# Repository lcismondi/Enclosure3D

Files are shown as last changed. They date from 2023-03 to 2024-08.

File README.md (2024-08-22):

# Enclosure3D
Me puse a diseñar un control de ambiente para un gabinete de impresión 3D y así mejorar la calidad de impresión, puedes ver más novedades en mis redes [Instagram](https://instagram.com/lucianociri) y [TikTok](https://www.tiktok.com/@luciano.ciri).

Montaje

 ### Componentes
 * NodeMCU ESP8266 (compatible con V2 y V3)
 * Display 0.91" oled
 * Sensor de humedad y temperatura DHT11 o DHT22
 * Rotary encoder

## Parámetros técnicos
* Dimensiones: 105mm x 65mm x 33mm
* Material: PLA
* Alimentación: 12v CC
* Consumo: 

## Puertos
El dispositivo presenta 3 salidas para el control de ambiente:
* Iluminación (LUZ) 12v @ 1A.
* Ventilación (VT1) 12v @ 1A.
* Ventilación (VT2) 12v @ 2A.

### Diagrama de conexionado

```mermaid
graph LR;
id0("Vcc 12v")-->id1[Enclosure3D];
id1[Enclosure3D]--pwm-->id2["Iluminación(LUZ)"];
id1[Enclosure3D]--pwm-->id3["Ventilación 1 (VT1)"];
id1[Enclosure3D]--pwm-->id4["Ventilación 2 (VT2)"];

id1[Enclosure3D]--i2c-->id5["Display 128x32"];
id6["Encoder"]-->id1[Enclosure3D];
id7["DHT"]-->id1[Enclosure3D];

```
# Proyecto
Es un proyecto Openfirmware en el cual se puede desarrollar sobre la arquitectura del ESP8266. Para saber más sobre el código puedes verlo y descargarlo desde la 
[sección de firmware](./Firmware/README.md) y si lo que más te gusta es diseñar, puedes proponer la próxima versión de la carcaza o personalizarla a tu propio estilo en la [sección de carcasa](./Carcasa/README.md).

# Compatibilidad
Como no todo sucede al mismo tiempo y en el mismo orden, veamos qué cosa es compatible con qué.

| [Firmware](./Firmware/Versiones.md) | [PCB](./PCB/VersionPCB.md)  | [Carcasa](./Carcasa/Versiones.md)  | Software |
| :--: | :--: | :--: | :--: |
| 0.0 | 0.0 | 0.0 | - |
| 0.1 | 0.1 | 0.1 | - |
| 0.2 | 0.2 | 0.2 | - |
| 0.3 | 0.3 | 0.2 | - |
| 0.4 | 0.3 | 0.2 | - |
| - | - | - | - |

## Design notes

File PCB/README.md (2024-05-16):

# Pinout

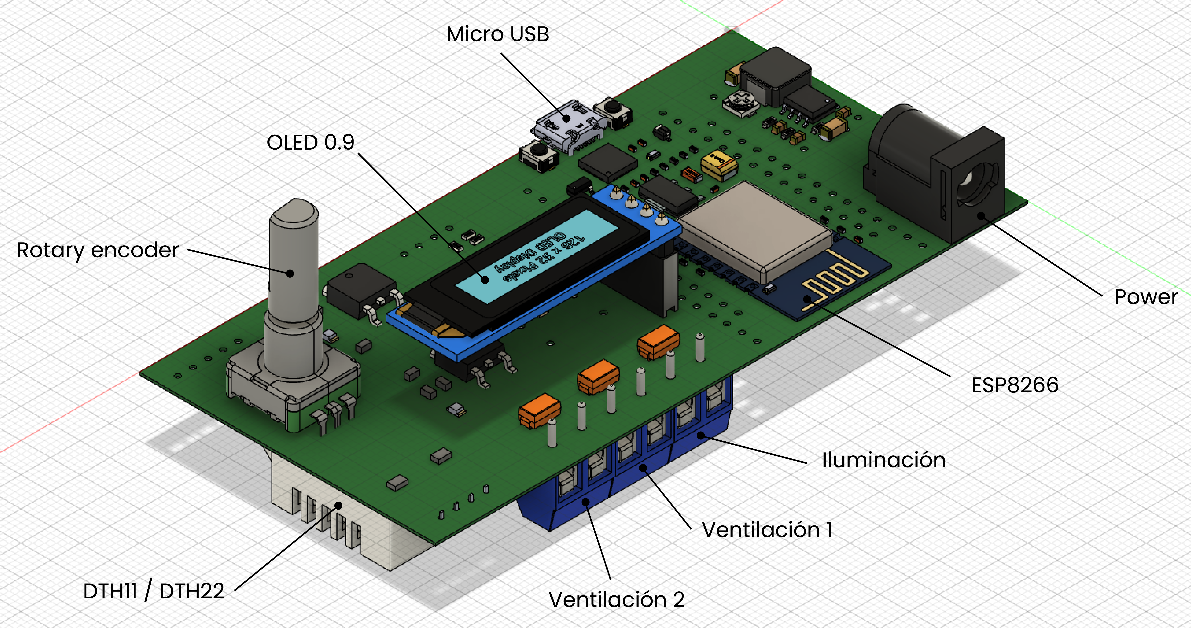
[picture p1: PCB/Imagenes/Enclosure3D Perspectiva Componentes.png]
Componentes internos


## Rotary encoder
* Switch: 13 [D7]
* Data:   12 [D6]
* Clock:  16 [D0]

## Salidas
* Iluminación:  15 [D8]
* Ventilador 1: 0  [D3]
* Ventilador 2: 14 [D5]

## Sensor
* Humedad y temperatura: 2 [D4]

## Display
* Reset: 16 [D0]
* Clock: 5  [D1]
* Data:  4  [D2]

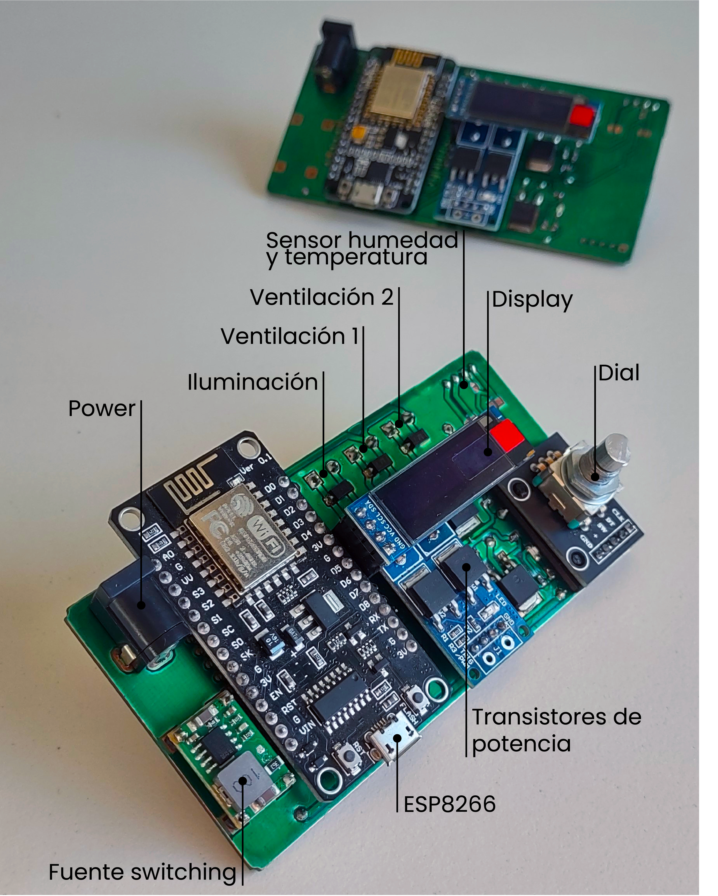
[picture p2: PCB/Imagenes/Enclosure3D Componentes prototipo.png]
Componentes prototipos


# Serigrafía
La versión de fabricación industrial tiene la capa de silkscreen mejor diseñada.

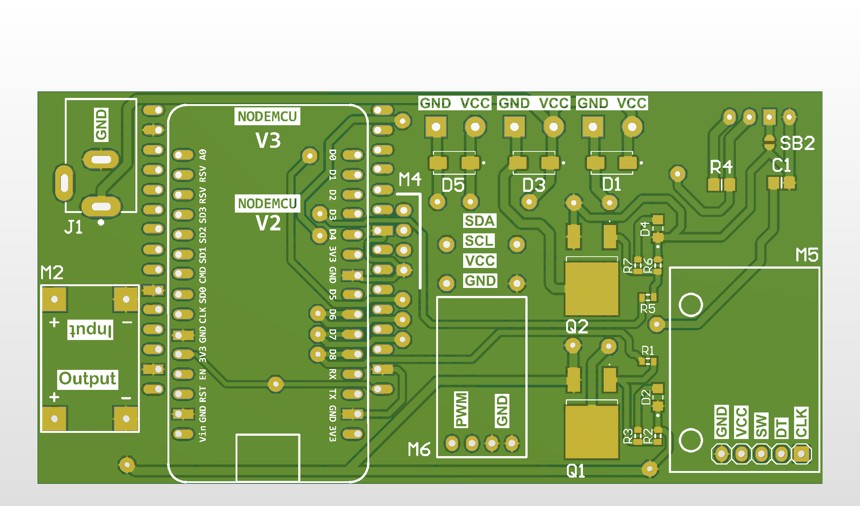
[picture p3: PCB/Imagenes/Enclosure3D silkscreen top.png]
Silkscreen top


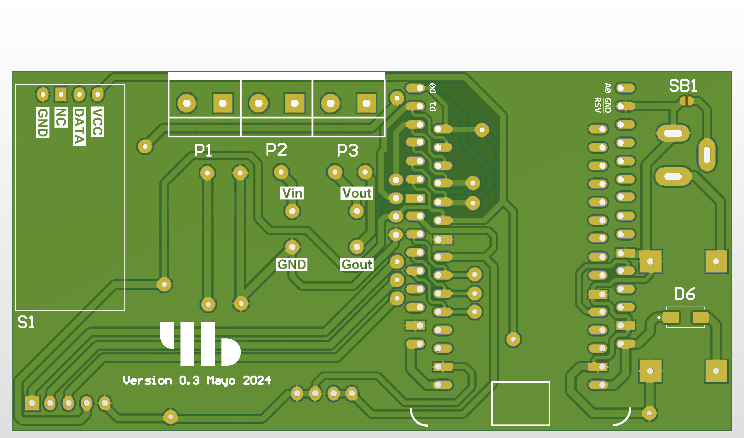
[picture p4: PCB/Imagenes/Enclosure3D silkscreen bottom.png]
Silkscreen bottom


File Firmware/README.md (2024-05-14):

# Descripción del Firmware

## Máquina de estados
El sistema está basado principalmente en una gran máquina de estados que gestiona el menú de interfaz de usuario y por otro lado la administración de la lágica de control del dispositivo.

```mermaid
graph TD;
    id0((Inicio))-->id1(Lectura botones);
    id1(Lectura botones)-->id2(Control Menú);
    id2(Control Menú)-->id3(Control lógica);
    id3(Control Lógica)-->id1(Lectura botones);
    
    id2(Control Menú)-->id4(Carrusel);
    id4(Carrusel)-->id2(Control Menú);
    
    id4(Carrusel)-->id5(Primer menú);
    id5(Primer menú)-->id4(Carrusel);
    
    id5(Primer menú)-->id6(Opción submenú);
    id6(Opción submenú)-->id5(Primer menú);
    
    id6(Opción submenú)-->id7(Configuración valores);
    id7(Configuración valores)-->id6(Opción submenú);
```

Las acciones de transición vienen dadas por el "click" del cursor de navegación dentro del menú.

## Espacios de memoria
El menú se reserva con un vector de vectores en donde todos los niveles son del mismo tamaño dado por el mayor. El final de un vector de menor tamaño lo determina la palabra clave "Volver".

| Menú  | 1° Renglon | 2° Renglon | 3° Renglon | 4° Renglon |
| :--: | :--: | :--: | :--: | :--: |
| Temperatura | Set point | Ripple | Unidad | Volver |
| Reloj|Modo | Tiempo | Reset | Volver |
| Ventilacion | Modo | Funcion | Velocidad | Volver |
| Iluminacion | Modo | Alarma | Brillo | Volver |
| *Wifi** | *Modo* | *SSIS* | *Nivel* | *Volver* |
| Sistema | Reiniciar | Encoder | Contraste | Volver |
|Salir|

**Funcionalidad no implementada*

Los valores se guardan en la memoria EEprom solo cuando sufren un cambio desde el menú de administración y se alojan en los siguientes espacios reservados:

    0x100 menuVal[0][0] = Temperatura medida
    0x104 menuVal[0][1] = Temperatura seleccionada
    0x108 menuVal[0][2] = Ripple
    0x112 menuVal[0][3] = Unidad temperatura
    0x116 menuVal[0][4] = Humedad medida
    0x120 menuVal[1][0] = -
    0x124 menuVal[1][1] = Modo reloj (Off/Cronometro/Temporizador)
    0x128 menuVal[1][2] = Tiempo en milisegundos
    0x132 menuVal[1][3] = Reset
    0x136 menuVal[1][4] = -
    0x140 menuVal[2][0] = -
    0x144 menuVal[2][1] = Modo ventilacion (Manual/Automatico)
    0x148 menuVal[2][2] = Función ventilación (Progresivo/Simultáneo)
    0x152 menuVal[2][3] = Velocidad PWM
    0x156 menuVal[2][4] = -
    0x160 menuVal[3][0] = -
    0x164 menuVal[3][1] = Modo iluminación (Off/On)
    0x168 menuVal[3][2] = Alarma iluminación (Off/On)
    0x172 menuVal[3][3] = Brillo PWM
    0x176 menuVal[3][4] = -
    0x180 menuVal[4][0] = Modo WIFI (Scan/AP)
    0x184 menuVal[4][1] = SSID
    0x188 menuVal[4][2] = Porencia dBm
    0x192 menuVal[4][3] = -
    0x196 menuVal[4][4] = -
    0x200 menuVal[5][0] = -
    0x204 menuVal[5][1] = Reinicio
    0x208 menuVal[5][2] = Sensibilidad rotary encoder
    0x216 menuVal[5][3] = Contraste pantalla
    0x220 menuVal[5][4] = -

Existe una opción de reinicio a modo de fábrica la cual, setea valores por defecto en estos espacios de memoria.

    menuVal[0][0] = 0
    menuVal[0][1] = 35
    menuVal[0][2] = 3
    menuVal[0][3] = 0
    menuVal[0][4] = 0
    menuVal[1][0] = 0
    menuVal[1][1] = 1
    menuVal[1][2] = 0
    menuVal[1][3] = 0
    menuVal[1][4] = 0
    menuVal[2][0] = 0
    menuVal[2][1] = 1
    menuVal[2][2] = 0
    menuVal[2][3] = 0
    menuVal[2][4] = 0
    menuVal[3][0] = 0
    menuVal[3][1] = 1
    menuVal[3][2] = 0
    menuVal[3][3] = 255
    menuVal[3][4] = 0
    menuVal[4][0] = 0
    menuVal[4][1] = 0
    menuVal[4][2] = 0
    menuVal[4][3] = 0
    menuVal[4][4] = 0
    menuVal[5][0] = 0
    menuVal[5][1] = 0
    menuVal[5][2] = 12
    menuVal[5][3] = 255
    menuVal[5][4] = 0

### Niveles del menú

El nivel cero es un carrusel el cual muestra dos pantallas rotativas cada 3 segundos, luego al hacer click con el cursos ingresa al primer nivel de menú en el cual se selecciona la opción a configurar, para ingresar a un segundo submenú en donde se elije el valor final que se desea personalizar.

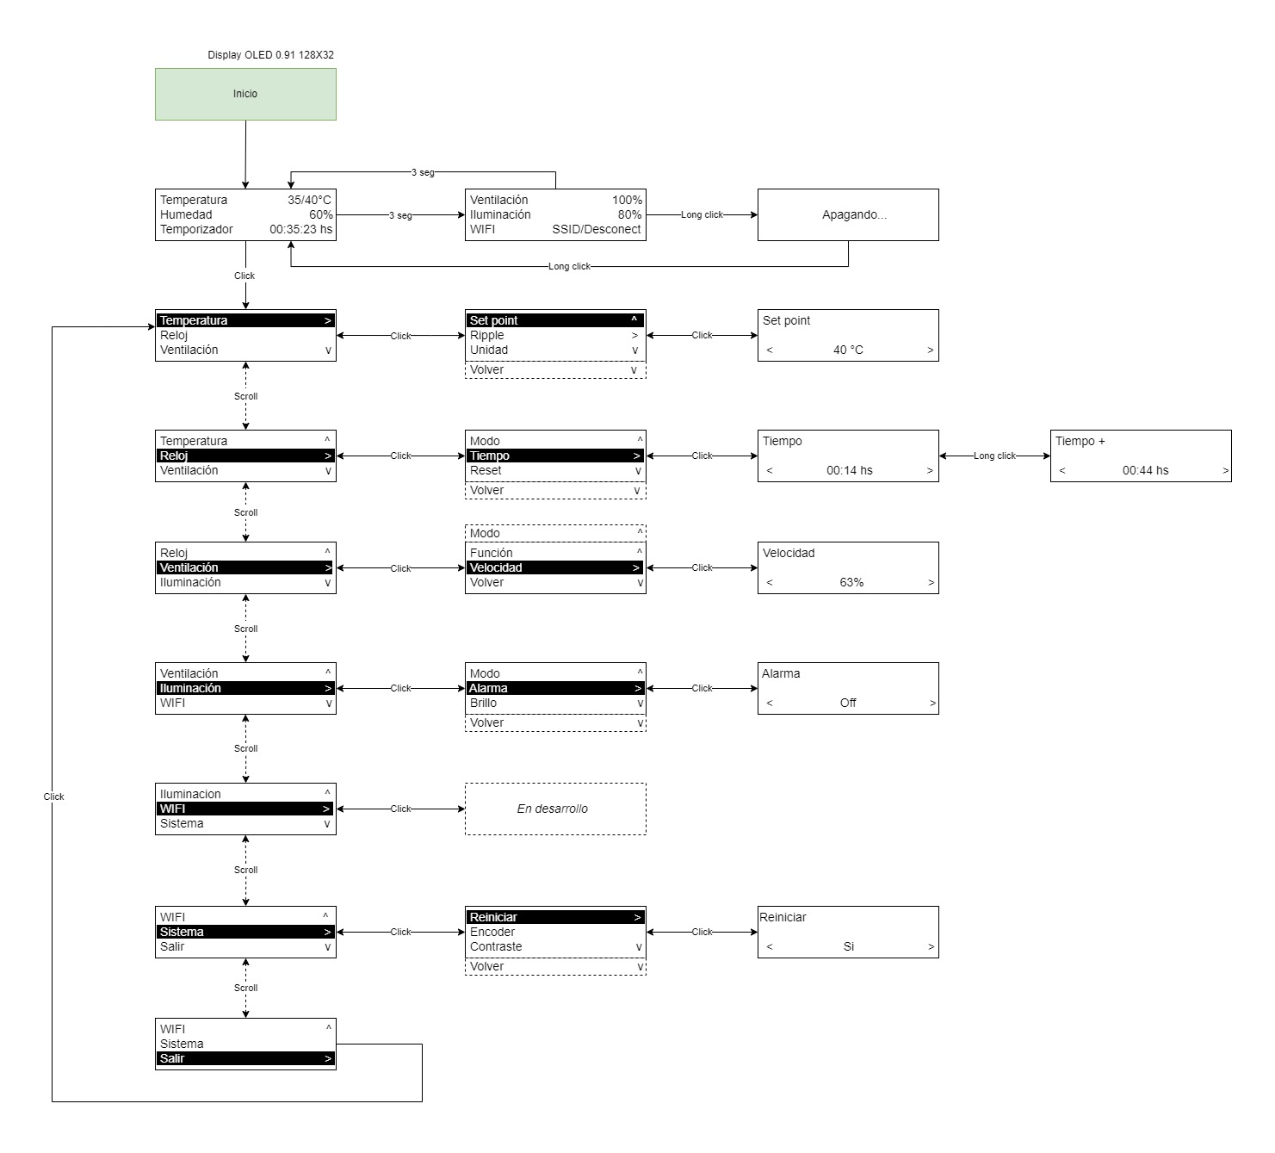
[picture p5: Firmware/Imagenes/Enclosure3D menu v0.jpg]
Diagrama pantallas


## Funcionalidades

### Longpress (5 seg)
En algunas ocaciones se puede mantener presionado el cursor para destrabar una segunda función al click. Por defecto, mantener presionado el botón por 5 segundos y luego soltarlo, ejecuta una segunda función, esta última acciona al soltar el botón.

### Apagado y encendido
Al conectar el jack de alimentación (12v) el equipo naturalmente enciende. Para apagar el equipo definitivamente se lo debe desconectar, pero tiene una función "Stand by" la cual se activa manteniendo presionado el botón por 5 segundos. En este modo el equipo corta todas las salidas y apaga la pantalla
Para encenderlo se realiza el mismo procedimiento, se mantiene presionado el botón por 5 segundos y el equipo vuelve a encerder.

### Stand by
Si el equipo transcurre más de 10 minutos sin ninguna actividad en los movimientos del cursor y la temperatura ambiente por debajo del set point entra en un modo stand by en donde solo queda monitoreando el estado de la temperatura para volver a encerder si algún evento lo despierta, como puede ser que la temperatura supere el set point seleccionado.

# Modos

## Temperatura
Aquí se puede configurar la _temperatura_ a partir de la cual el sistema controla el ambiente. Este parámetro trabaja en conjunto con el _riple_ el cual dará un rango de acción alrededor del valor de temperatura seleccionado. Dependiendo de la función de ventilación su comportamiento será distinto.
Por último también se puede cambiar la unidad de °C a °F. El sistema recalcula los valores para mantener la compatibilidad.

## Reloj
Configuración del tiempo mostrado en la pantalla del carrusel.

### Temporizador
Al iniciar el equipo o al resetear el reloj (Reloj >> Reset) comienza a contar el tiempo en la pantalla del carrusel. Se puede elegir la base desde donde comienza a contar en el menú Rejoj >> Tiempo. Se utiliza la misma base de tiempo tanto para el temporizador y el cronómetro.

### Cronómetro
De forma similar al modo temporizador, pero de manera inversa. Al iniciar el equipo o al resetear el reloj (Reloj >> Reset) comienza a contar el tiempo de forma descendente en la pantalla del carrusel. Se puede elegir la base desde donde comienza a contar en el menú Rejoj >> Tiempo.

## Ventilación
Puede ser manual o automático. En el modo manual se puede seleccionar la velocidad desde el menú (Ventilación >> Velocidad), la cual fija la velocidad de los ventiladores indistintamente de la temperatura que tenga en gabinete controlado.
En caso de seleccionar automático, el sistema regula la velocidad de los ventiladores en función de la temperatura interna del gabinete, la seteada como referencia (set point) y el riple.
Ambos modos se van a ver afectados por el tipo de función de ventilación seleccionada.

La función de ventilación busca disminuir el ruido ocacionado por los ventiladores. Existen tres formas de trabajo:
* Progresivo, a bajas potencias enciende solo un ventilador, a potencias medias enciende dos ventiladores y cuando requiere extraer mucho volumen termina encendiendo los tres ventiladores. Cada una de las etapas de encendido son escalonadas.
* Simultáneo, en esta forma de trabajo se encienden los tres ventiladores juntos con el nivel de potencia requerido para garantizar la estabilida de la temperatura interna.
* Riple, es una convinación de ambas anteriores pero utilizando solo 0% y 100% de potencia de cada ventilador, es decir, apagado o encendido. Esta función se utiliza para aquellos coolers que no soporten control por PWM y oscilen con ruido audible. 

## Iluminación
Al igual que desde el dial en el carrusel principal, desde este menú se puede regular la intensidad de la iluminación del gabinete, tanto encenderlo como apagarlo.
_El modo alarma está en desarrollo y se relaciona con la configuración del temporizador al llegar a cero con indicadores lumínicos._

## Wifi
_En desarrollo (futuras versiones). El objetivo es que pueda dar avisos de intado y poder controlar/configurar el dispositivo desde una webapp._

## Sistema
Permite configurar algunas características del equipo.
* Reinicio, vuelve a los parámetros de "modo de fábrica".
* Encoder, configura la sencibilidad del dial de rotación.
* Contraste, regula la visualización de la pantalla.

## Funciones

### void display2 (void)
Actualiza la segunda pantalla del carrusel, se utiliza para activar la función de iluminación en el acto. Al estar situado en el carrusel, si se gira el cursor se puede ajustar el nivel de iluminación sin que este implique actualizar el seteo por default en el brillo. Cuando el equipo vuelve a encender tomará como parámetro el valor que tenga en Iluminación >> Brillo.

### void renglones (String, String, String, int)
Gestiona el sombreado de los renglones del menú y la colocación de las flehas de navegación. Trabaja en conjunto con los displayLnl's.

### void displayLvl1(int)
Dependiendo de la posición del cursor imprime de forma dinámica los renglones siguientes y anteriores.
*Puede tener problemas para imprimir líneas de menú con menos de 3 ítems.*

### void displayLvl2(int, int)
Dependiendo de la posición del cursor y el menú seleccionado imprime de forma dinámica el submenú.
*Es importante limitar el submenú con la palabra especial "Volver".*

### void displayLvl3(int, int)
Administra el cambio de las variables finales y tiene condiciones de personalización para cada tipo de dato.

### void printHorario (void)
Salida por terminal para bugging, imprime estado de los cursores para giros horarios.

### void printAntihorario (void)
Salida por terminal para bugging, imprime estado de los cursores para giros antihorarios.

### void printBoton (void)
Salida por terminal para bugging, imprime estado de los cursores al presionar.

### void progresivo(byte)
Trabaja en función de "power". Con la siguiente condición:
* Para potencias por debajo de 30% enciende solo un ventilados.
* Para potencias entre 30 y 70% enciendo dos ventiladores.
* Para potencias mayores al 70% enciente los tres ventiladores.

### void power(void)
Determina el nivel de potencia aplicada al sistema de ventilación.
* Si se encuentra por debajo del límite inferior del (set point - riple) no enciende.
* Entre el límite inferior del (set point - riple) y el set point, enciende progresivamente hasta el 50%.
* Entre el set point y el límite superior del (set point + riple), enciende progresivamente hasta el 100%.
* Si se encuentra por sobre del límite superior del (set point + riple) enciende a máxima potencia.

# Releases
Para ver las características de cada una de las versiones ir a [Versiones.md](./Versiones.md)

# Puertos
Para entender un poco más qué controla cada uno de los puertos de salida, probablemente quieras ver un poco más sobre el [diseño del PCB](../PCB/README.md).

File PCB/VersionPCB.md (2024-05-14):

# Versiones del PCB
Algunas mejoras y cambios al hardware del proyecto.

## V0.3: Fabricación
* [Diodo de protección fuente switching](../PCB/Fuente%20switching.md)
* Etiquetas silkscrren
* Fabricación PCBway
  
## V0.2: Mejoras postproceso DIY
* Corrección de errore en footprint

## V0.1: Inicial
* Diseño básico

## Versiones futuras:
* Filtro RC de salida para PWM
* Vías e integración

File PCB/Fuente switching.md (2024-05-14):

# Fuente mini 360

Basado en el [MP2307](https://cdn-shop.adafruit.com/datasheets/MP2307_r1.9.pdf), la fuente tiene regulación de tensión de salida, por lo cual por seguridad se hace una modificación con el fin de dejar fija la tensión de salida en 5V. Esta tensión es la misma que alimenta el microcontrolador ESP8266.
Originalmente el módulo tiene un divisor resistivo conformado por una resistencia de 8.2K y un potenciómetro.

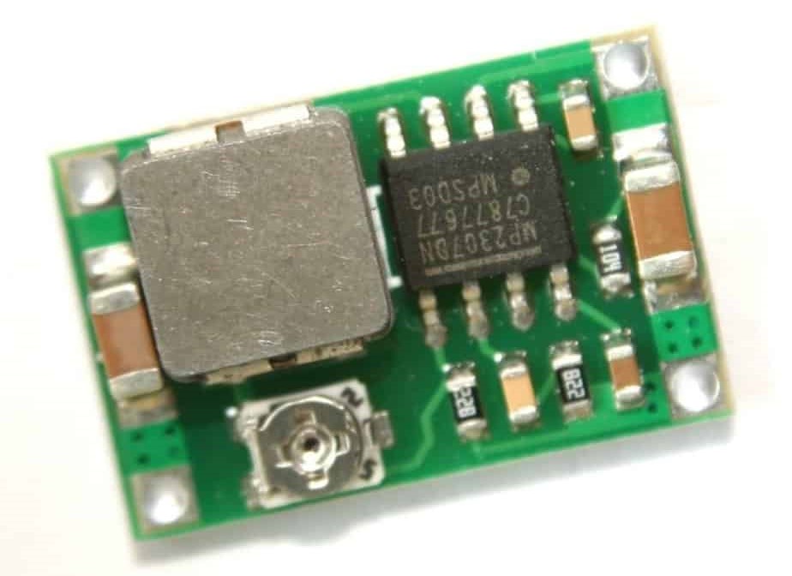
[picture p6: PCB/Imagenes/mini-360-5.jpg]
Modulo


La tensión de salida se regula según la siguiente ecuación:

$V_{OUT}=0.925.\frac{R_1+R_2}{R_2}$

Siendo R2 de 8.2K, el valor de la resistencia R1 debe ser de 36K, con lo que se obtienen 4.98V de salida.
Al levemente inferior a 5V puede generar un recalentamiento de la fuente cuando se enchufa el puerto USB del kit de desarrollo.

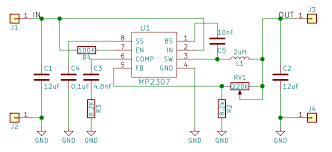
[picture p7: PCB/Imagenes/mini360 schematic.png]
schematico


Con resistencias 1206 queda bien, pero también se podrá probar con 0805.

En caso de colocar un diodo de proyección a la salida, hay que tener en cuenta la caída del diodo, típicamente 0.7v.

$V_{OUT}=0.925.\frac{R_1+R_2}{R_2}=5.7V$

Siendo R2 de 8.2K, el valor de la resistencia R1 debe ser de 42K, con lo que se obtienen 5.77V de salida.

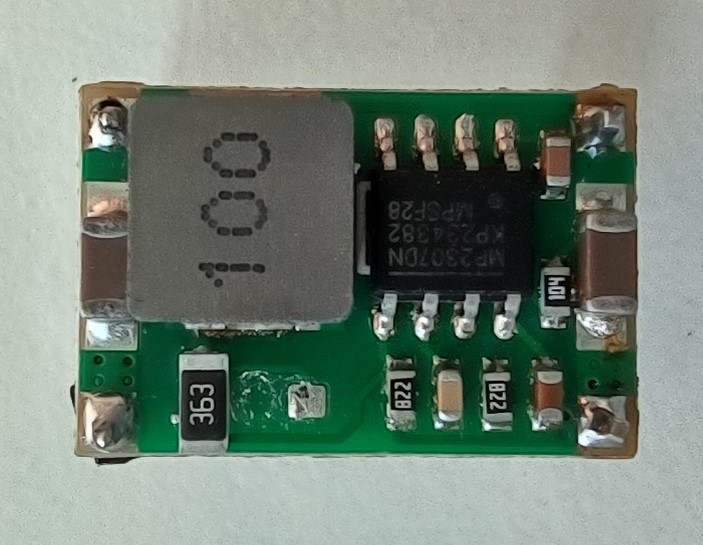
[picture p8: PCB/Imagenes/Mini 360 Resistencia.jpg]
Resistencia


Información de desempeño de la fuente [en este link](https://www.matts-electronics.com/wp-content/uploads/2018/06/MINI-360.pdf)

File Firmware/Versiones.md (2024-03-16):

# v0.4: Modo ripple
 * Modo riple ventiladores 0 - 100% (por el ruido de oscilacion)
 * [Bug rebote encoder](./Bug%20rebote%20rotary%20encoder.md)
 * Estandarización boton longpress

# V0.3: Apagado
 * Longpress por tiempo en vez de pulsos
 * Longpress apagado
 * Pantalla alarma
 * Presionar botón para despertar sin acción menú
 * Bug longitud de memoria
 * Bug control progresivo
 * Bug control de potencia cooler
 * Despertar al cambiar la potencia

# V0.2: MCU esp8266
 * Eeprom update float
 * Rotary debounce
 * Bug commit eeprom
 * Flechas navegación level 3
 * En iniciando espera temperatura y humerar
 * Reset modo fábrica cargar variables en memoria
 * Botón long press
 * Long press tiempo reloj horas
 * Carrusel tiempo continuo display
 * Límite de setpoint y riple para unidad de medida
 * Al cambiar la unidad de medida guarda los nuevos valores. setpoint y riple.
 * Temperatura °F/°C, con conversión
 * Centrar modos level 3
 * Reset contador de reloj
 * Auto suspención pantalla

# V0.1: Bug rotary encoder
 * Zig-zag bug y switch antirrebote
 * Manejo de memoria EEPROM (No tiene interna)

# V0.0: Versión inicial
 * Rotary encoder
 * Push button
 * Termómetro y Humedad
 * Display y menú

# Vxx: Futuro
 * Eeprom mapa de bits update
 * Flechas dinámicas level 3
 * Funciones level 3 fuera de rango "módulo" A%B
 * Menú configuración
	 Sencibilidad rotary encoder (debounce)
	 Segundos rotación pantalla
	 Sentido pantalla
	 Paso dial de luz
 * Calibración temperatura
 * Bloqueo inicialización sensor de humedad
 * Ver de actualizar valores dentro o fuera del switch
 * Estados por nombre del titulo en vez de por indice del vector
 * Idioma, inglés, Español
 * Longpress por tiempo en vez de pulsos
 * Longpress apagado
 * Arranque cooler bajas vueltas

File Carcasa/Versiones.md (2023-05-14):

# Versión 0.2: Encoder
 * Inserción y tamaño rueda
 * Ajuste USB
 * Anillo apoyo encoder
 * Apoyo esp8266 sobre la carcaza superior
 * Tamaño nombre de versión
 * Alineación gruías borneras

# Versión 0.1: Cierre módulo ESP
 * Cono 1mm tornillo de fijación sobre carcaza
 * Corrección sensor de humedad
 * Tamaño longitudinal carcaza +0.8
 * Corrección tamaño display
 * Corrección tamaño borneras
 * Altura botones logo
 * Álgulo ventilación módulo ESP
 * Ajuste jack alimentación
 * Altura boca USB
 * Nombre y fecha versión carcaza
 * Rueda 10mm

# Versión 0.0: General
 * Carcaza sin soportes
 * Rueda
 * Soporte

# Versión futuras:
 * Más canales de precintos
 * Soporte otras direcciones

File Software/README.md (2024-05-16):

El objetivo es lograr una versión que se pueda administrar desde el dispositivo movil sin necesidad de tener una aplicaciones previamente instalada. Mediante websockets y una webapp almacenada en el microcontrolador, conectarse al hotspot del esp8266 y tener los mismo parámetros de configuración que desde el dial.

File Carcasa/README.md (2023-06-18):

# Explotada

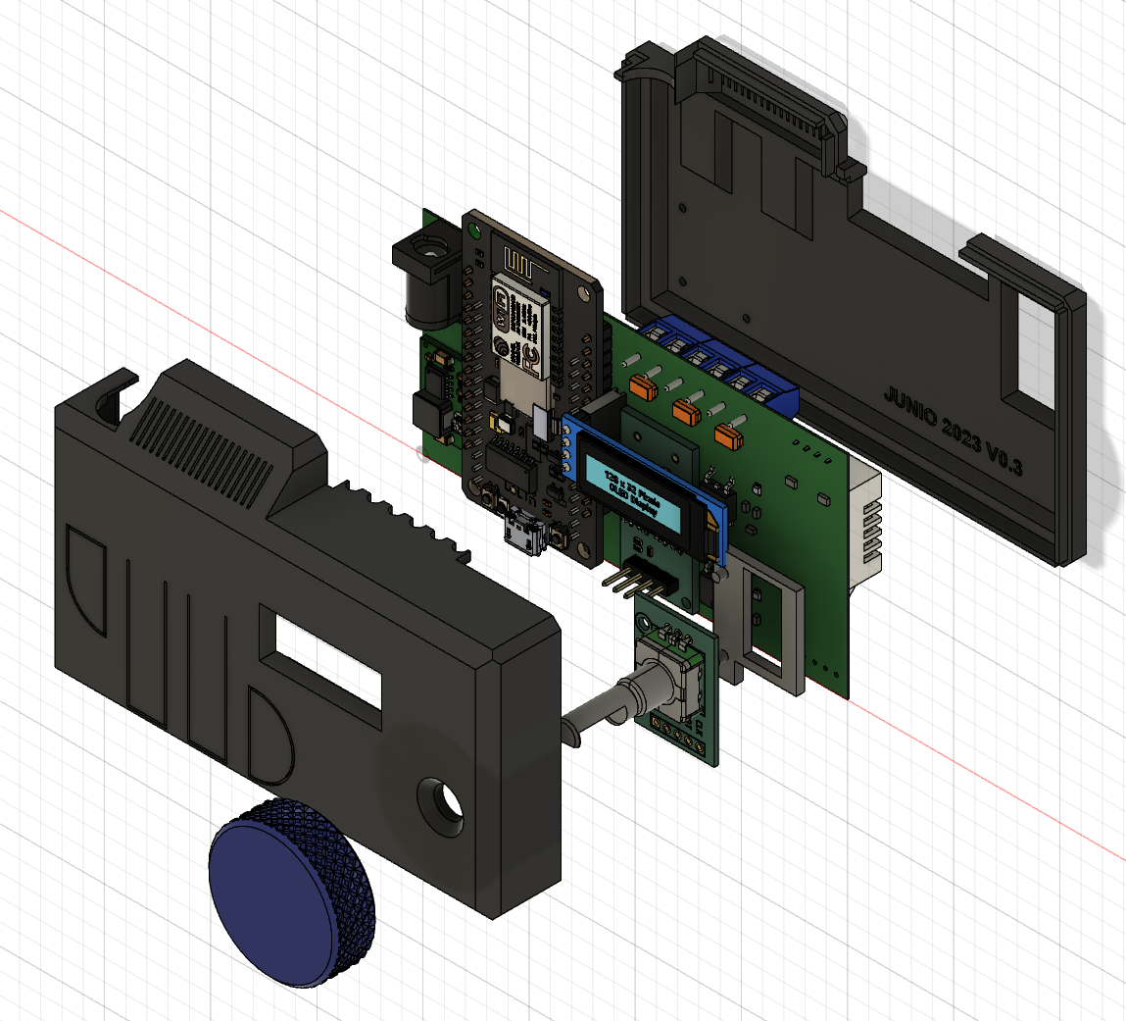
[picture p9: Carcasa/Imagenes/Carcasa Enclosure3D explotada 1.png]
Explotada


# Soportes
La carcaza principal tiene la posibilidad de diseñar múltiples soportes a la medida y a la necesidad de la ocación, solo es necesario respetar los parámetros de colocación de los tornillos.

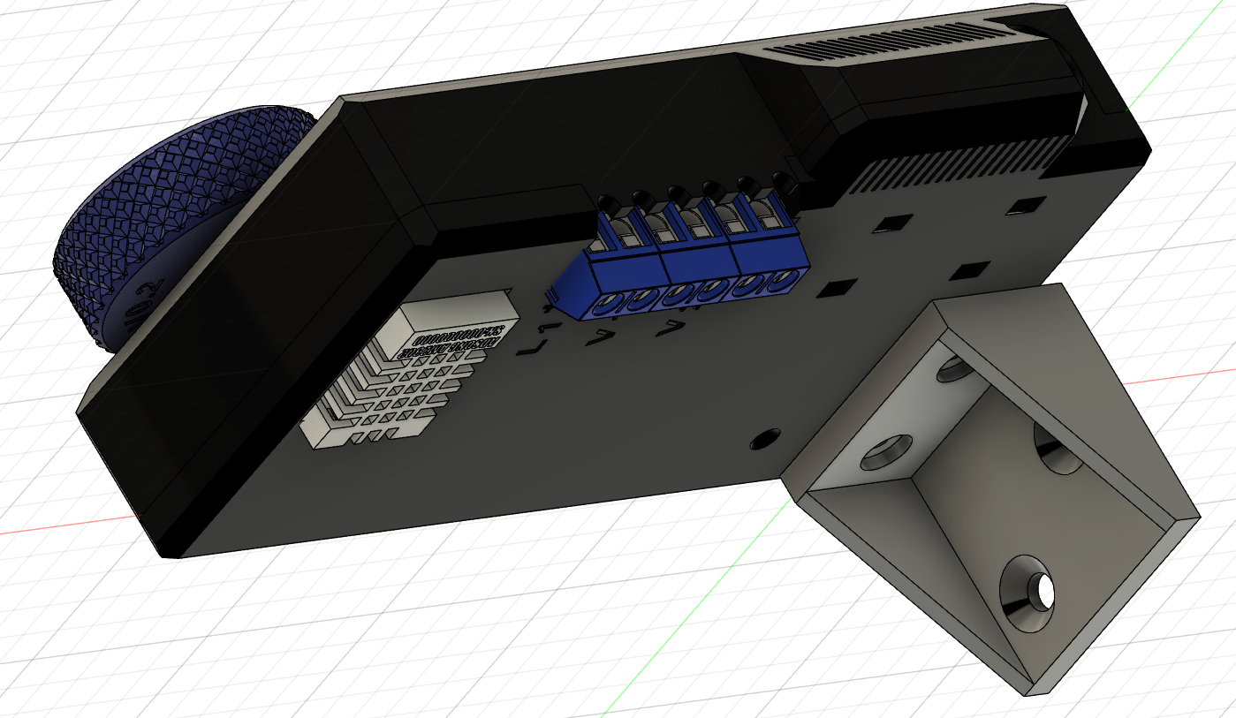
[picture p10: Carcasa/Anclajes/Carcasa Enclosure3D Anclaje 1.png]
Anclaje modelo 1

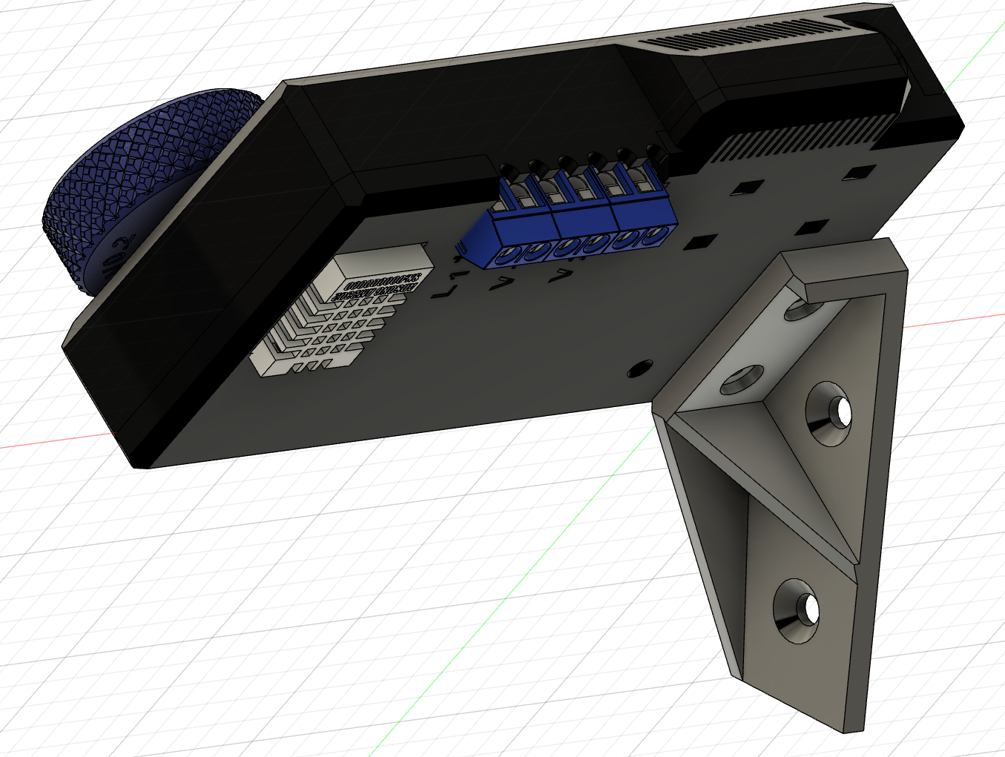
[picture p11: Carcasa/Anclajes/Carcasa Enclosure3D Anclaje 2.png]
Anclaje modelo 2


Para ver los modelos disponibles ir a [modelos de anclajes](./Anclajes/README.md). También podes compartir los tuyos!

# Plantilla
Las dimensiones de fijación son simátricas tanto horizontal como verticalmente, lo que permite rotar el anclaje para colocarlo en una nueva posición. En caso de que necesites adarptar el soporte a tu necesidad debes respetar las siguientes medidas:

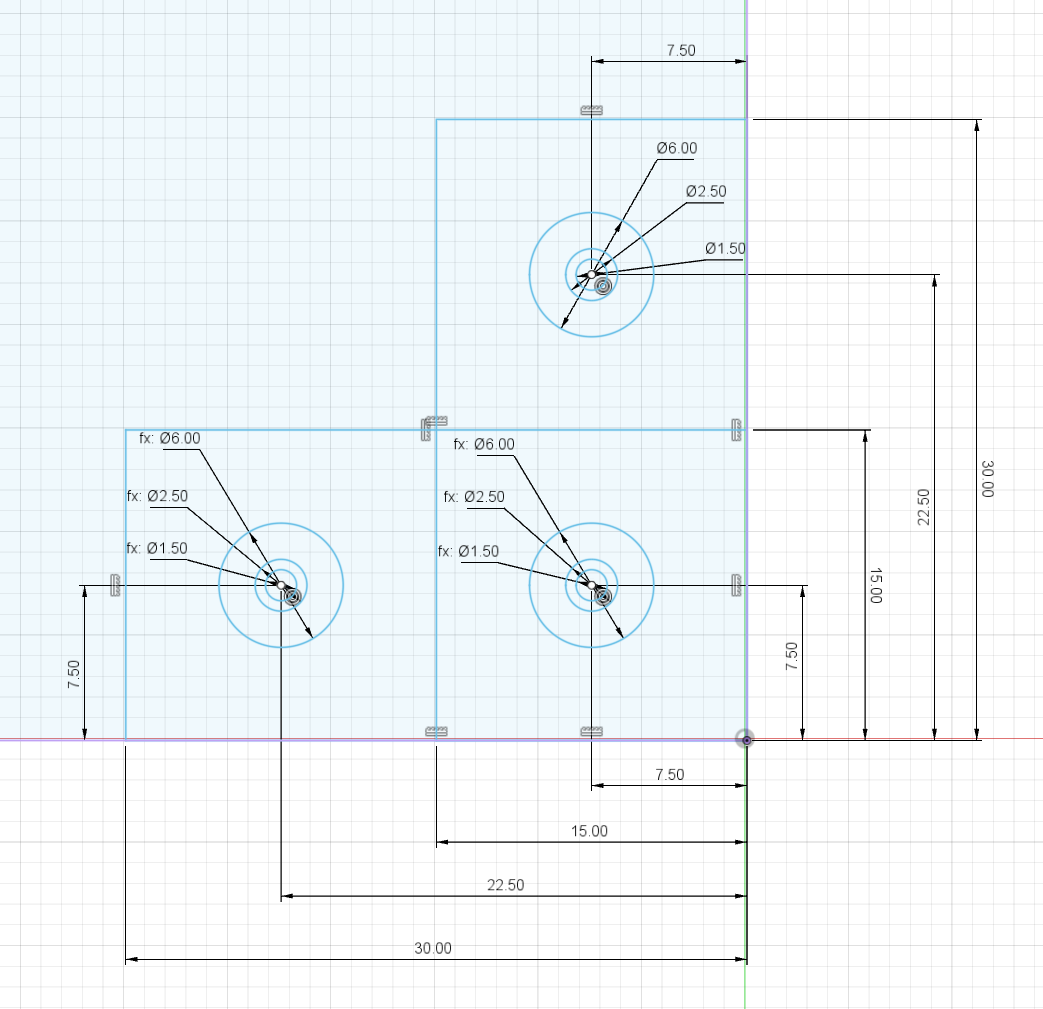
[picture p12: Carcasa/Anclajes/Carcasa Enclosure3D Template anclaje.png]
Template anclajes


# Releases
Para ver las características de cada una de las versiones ir a [Versiones.md](./Versiones.md)

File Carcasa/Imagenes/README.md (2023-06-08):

# Perspectiva
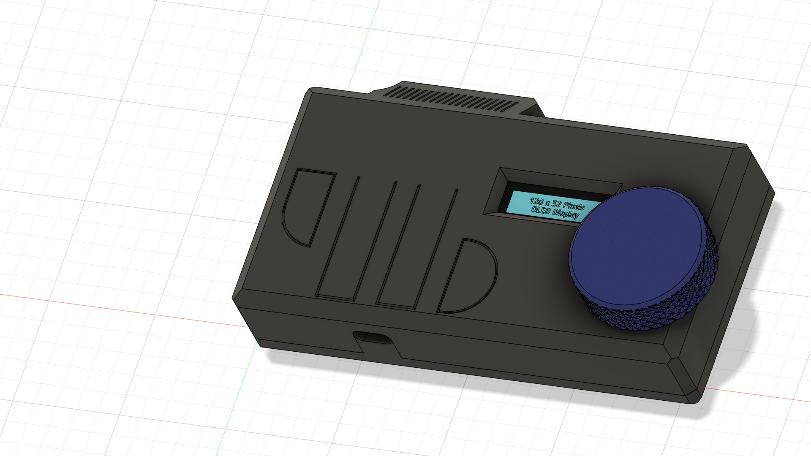
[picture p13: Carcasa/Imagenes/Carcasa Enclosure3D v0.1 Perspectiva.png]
Perspectiva


# Vista superior
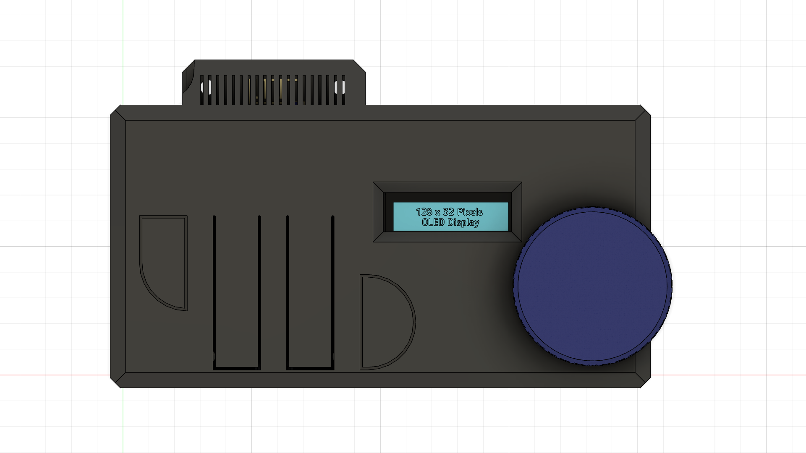
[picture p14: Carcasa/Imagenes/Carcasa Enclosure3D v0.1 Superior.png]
Superior


# Vista inferior
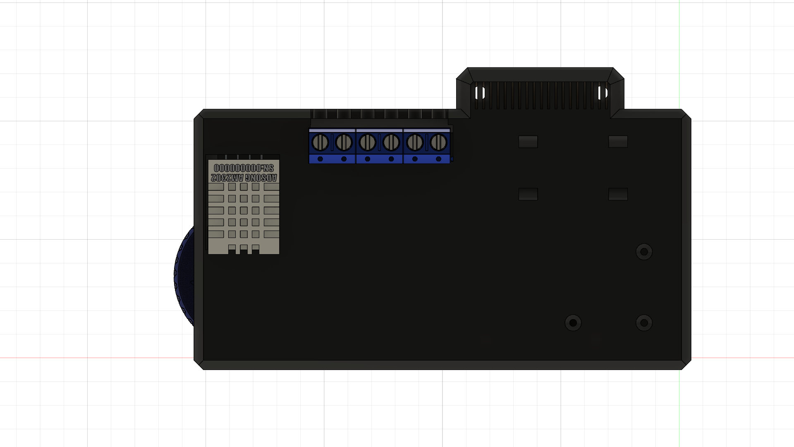
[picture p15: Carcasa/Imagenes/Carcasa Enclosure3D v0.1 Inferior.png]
Inferior


# Vista borneras
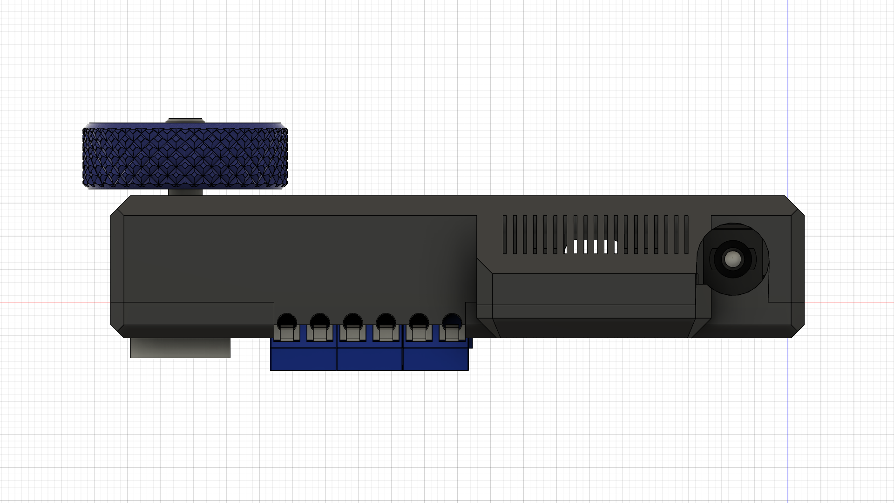
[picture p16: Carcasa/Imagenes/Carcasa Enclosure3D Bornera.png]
Borneras


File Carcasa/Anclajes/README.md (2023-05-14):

# Modelo 1
Anclaje modelo 1

# Modelo 2
Anclaje modelo 2

# Plantilla
Template anclajes

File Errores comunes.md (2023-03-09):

# Errores comunes

_1. El display se reinicia al mover el selector del dial_   
 Este problema se debe comunmente por un error en el inicio del dispositivo. Tiene que ver con que las variables de entorno no se pudieron cargar correctamente desde la memoria eeprom.
  Se soluciona reiniciando a modo de fábrica el dispositivo o cargando el firmware de grabado de memoria.

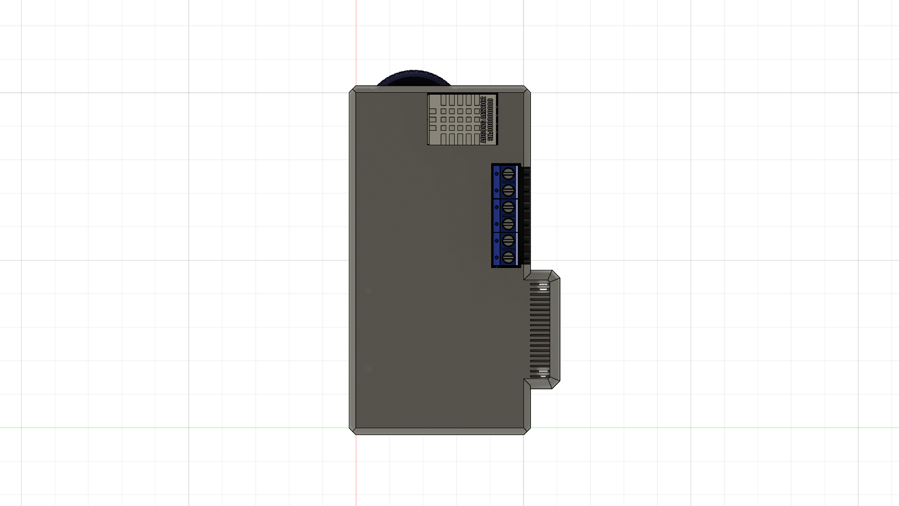
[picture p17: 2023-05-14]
Carcasa/Imagenes/Carcaza Enclosure3D v10 5.png

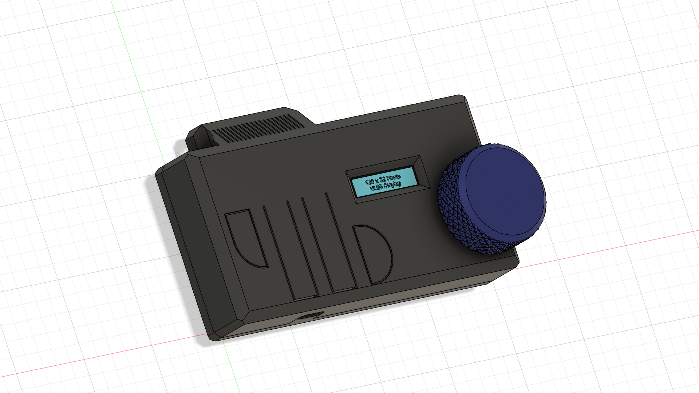
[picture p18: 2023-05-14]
Carcasa/Imagenes/Carcaza Enclosure3D v10.png

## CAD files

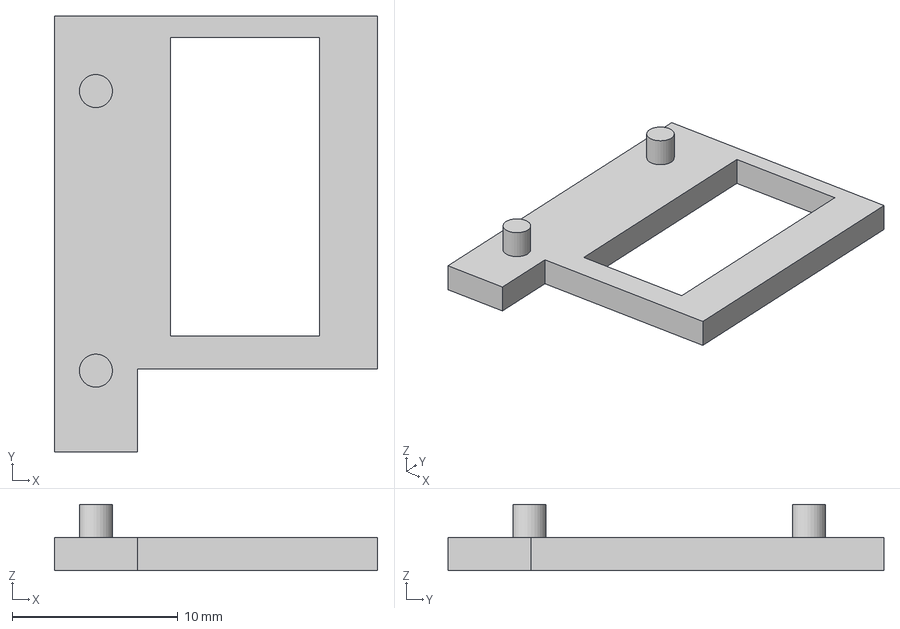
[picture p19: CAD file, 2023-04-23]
Carcasa/Soporte rotary encoder v0.1.3mf
19.5 x 26.3 x 4.00 mm

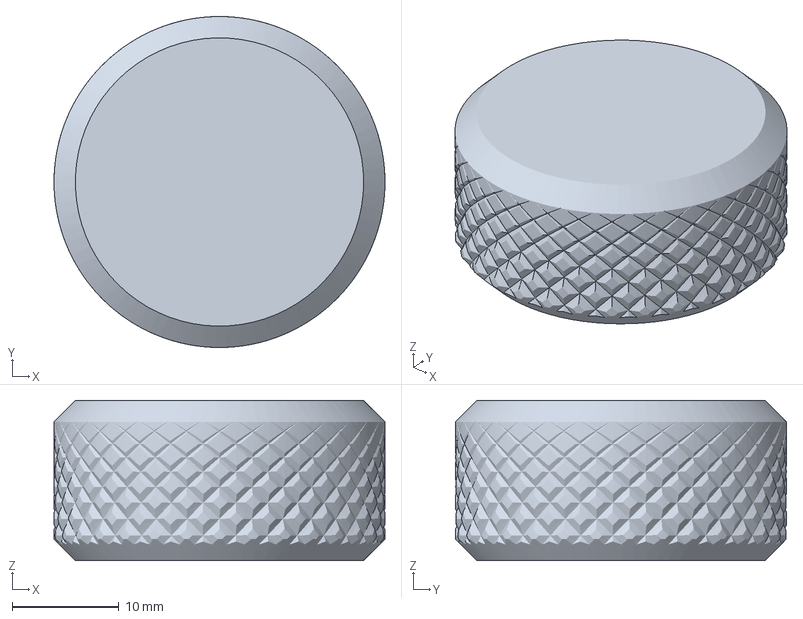
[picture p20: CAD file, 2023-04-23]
Carcasa/Rueda 15mm V0.0.3mf
31.0 x 31.0 x 15.0 mm

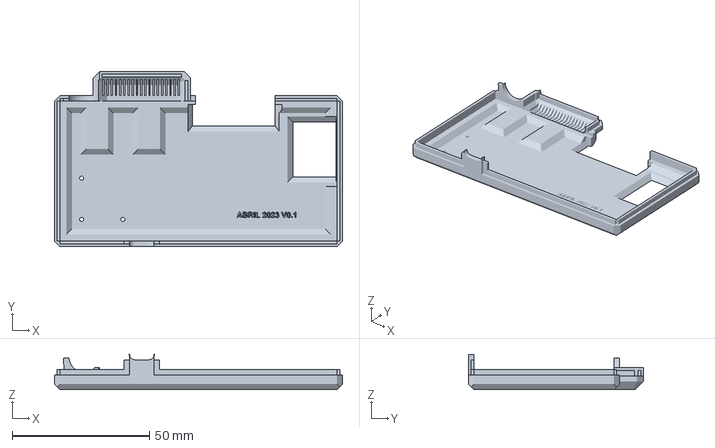
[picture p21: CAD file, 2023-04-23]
Carcasa/Carcasa inferior V0.1.3mf
105.0 x 63.8 x 12.9 mm

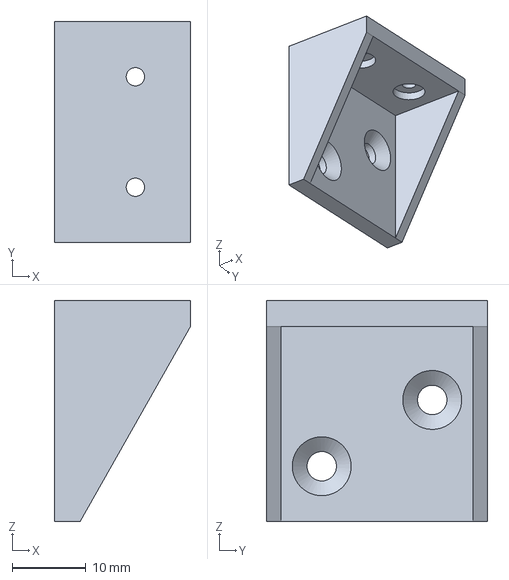
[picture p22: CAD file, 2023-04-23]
Carcasa/Anclaje v0.0.3mf
18.5 x 30.0 x 30.0 mm

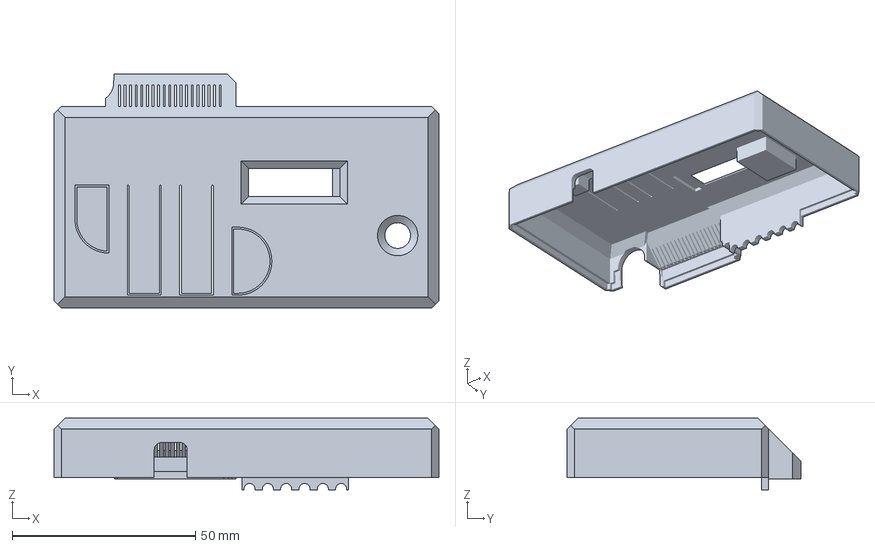
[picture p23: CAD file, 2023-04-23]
Carcasa/Carcasa superior V0.1.3mf
105.0 x 63.8 x 19.5 mm

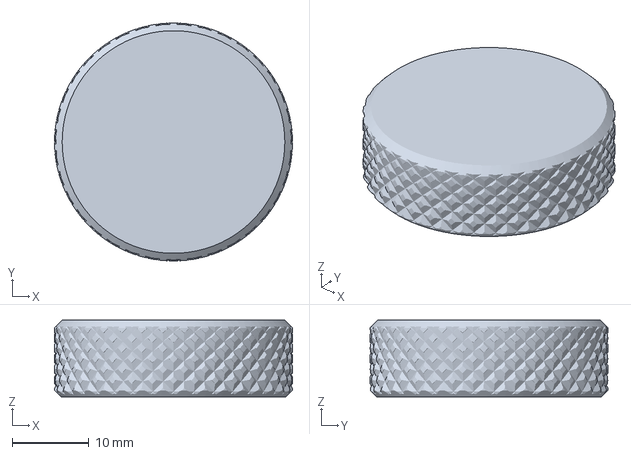
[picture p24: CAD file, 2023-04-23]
Carcasa/Rueda 10mm V0.1.3mf
31.0 x 31.0 x 10.0 mm

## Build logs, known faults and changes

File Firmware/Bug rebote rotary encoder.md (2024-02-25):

# Encoder Rotativo Ky-040 de 20 Pasos por vuelta

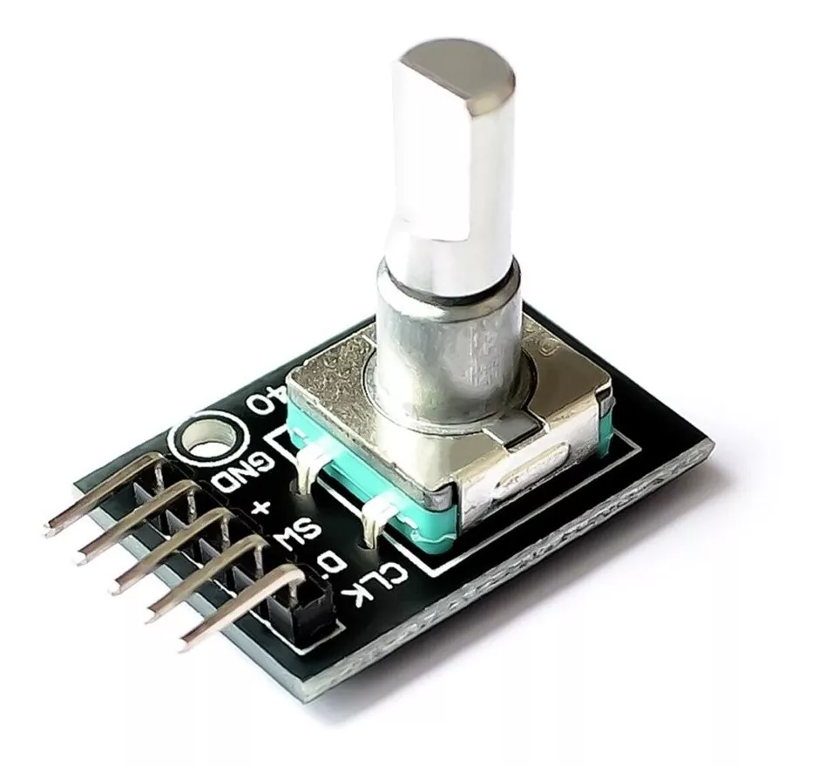
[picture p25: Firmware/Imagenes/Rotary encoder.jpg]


Los códigos tradicionales lo que hacen es leer el estado de una señal (CLK) y cuando esta cambia de estado leen el estado de la otra línea (DT). Dependiendo del valor de esta última interpretan si el cursor se mueve en un sentido u el otro.
Esta técnica funciona siempre y cuando el encoder tenga una buena calidad, en el caso de los componentes económicos típicamente chinos, no es tan así, teniendo falsos resultados sin que el encoder haya completado un paso.
Normalmente implementado como el siguiente código:

```
  currentStateCLK = digitalRead(CLK); 
  if (currentStateCLK != lastStateCLK && currentStateCLK == 1) { 
  currentStateDT = digitalRead(DT); 
    if (currentStateDT != currentStateCLK) { 
      counter++; 
      currentDir = "CCW"; 
    } else { 
      counter--; 
      currentDir = "CW"; 
    } 
  } 
  lastStateCLK = currentStateCLK; 
```

La señal obtenida en condiciones normales ([código grey](https://es.wikipedia.org/wiki/C%C3%B3digo_Gray)) son las que se muestran más abajo. 
Si se prueba en un sistema aislado lo más probable es que funcione correctamente, pero al ir incorporando más funcionalidades al microcontrolador y que este tenga que atender a más tareas, van a comenzar a aparecer los errores. Los invito a analizar paso a paso todas las posibilidades teniendo como referencia el código anterior y las señales para encontrar los casos de posibles fallas.

**Señal con giro horario:**
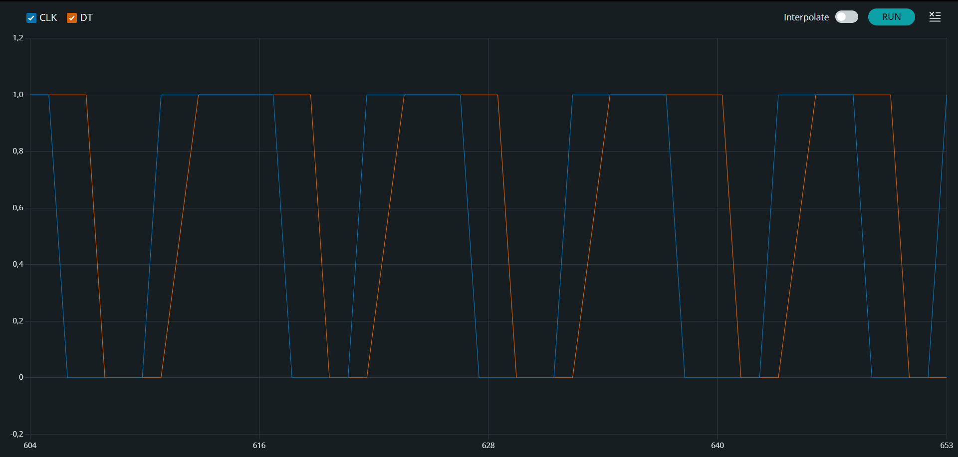
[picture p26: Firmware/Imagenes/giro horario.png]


**Señal con giro antihorario:**
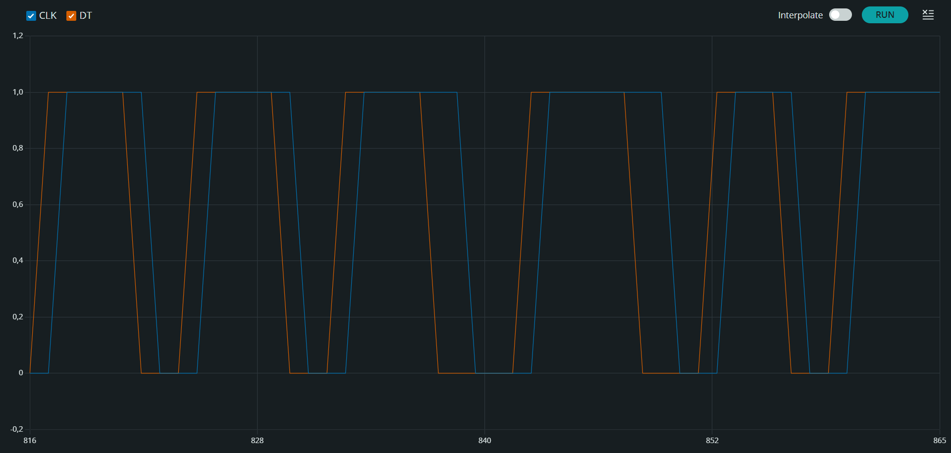
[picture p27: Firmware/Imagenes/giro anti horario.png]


## Error de secuencia
Existen casos en los que sí el potenciómetro no llega al próximo punto de giro y vuelve, esto genera un falso paso lo que puede provocar una lectura errónea. La señal que se obtiene en estos casos son las que están debajo:

**Error con giro horario:**
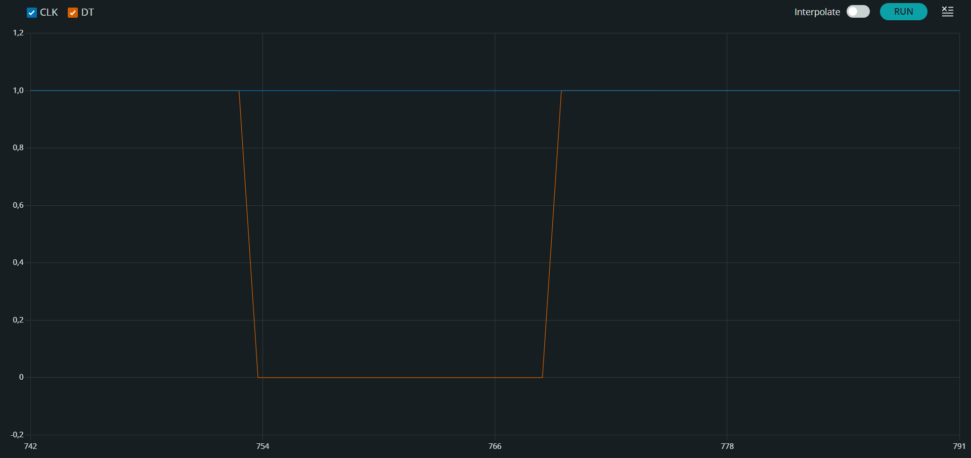
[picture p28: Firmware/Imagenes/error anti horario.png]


**Señal con giro antihorario:**
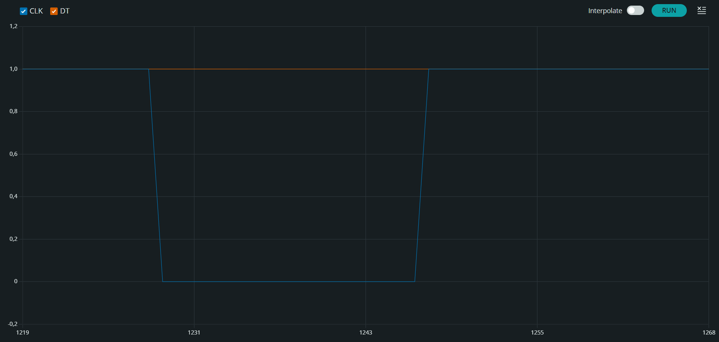
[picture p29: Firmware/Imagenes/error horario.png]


La solución es mirar el cambio de estado de ambas variables cuando la primera o una de ellas modifica su estado, esperar a que la segunda también lo haga, solo mientras la anterior se mantenga en su estado y dependiendo del sentido del cambio de la segunda será la dirección de giro.
Implementado se puede ver en el siguiente código:

```
  currentStateCLK = digitalRead(CLK);
  currentStateDT = digitalRead(DT);

  if (currentStateCLK == LOW && currentStateCLK != lastStateCLK) {
    flagCLK = HIGH;
    lastStateCLK = currentStateCLK;
  } else if (currentStateCLK == HIGH && currentStateCLK != lastStateCLK) {
    flagCLK = LOW;
    lastStateCLK = currentStateCLK;
  }

  if (flagCLK == HIGH) {
    if (currentStateDT == LOW && currentStateDT != lastStateDT) {
      counter++;
      currentDir = "CW";
      flagCLK = LOW;
    } else if (currentStateDT == HIGH && currentStateDT != lastStateDT) {
      counter--;
      currentDir = "CCW";
      flagCLK = LOW;
    }
  }
  else{
    lastStateDT = currentStateDT;
  }
```

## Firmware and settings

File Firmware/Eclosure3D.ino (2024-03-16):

#include <U8g2lib.h>
#include <DHT.h>
#include <EEPROM.h>

#define SW 13
#define DT 12
#define CLK 16

#define LUZ 15
#define VT1 0
#define VT2 14  //Pin 14 comparte con eeprom? Posible error

#define DHTPIN 2

//#define DHTTYPE DHT11  // DHT 11S
#define DHTTYPE DHT22  // DHT 22  (AM2302), AM2321


//DHT11   0 < Temperatura < 50°C | 20 < humedad <  90 %
//DHT22 -40 < Temperatura < 80°C |  0 < humedad < 100 %

/*  Utiliza el valor de GPIO

  A0   A0   ADC
  NC   Reservado
  NC   Reservado
  S3   10   GPIO
  S2   09   Reservado
  S1   08   Reservado
  SC   11   Reservado
  SO   07   Reservado
  SK   06   Reservado
  GND
  3.3V
  EN   Enable
  RST  Reset
  GND
  VIN


  D0   16   GPIO*
  D1   05   SCL(I2C)
  D2   04   SDA (I2C)
  D3   00   GPIO (pull up)*
  D4   02   GPIO (pull up)[LED]
  3.3V
  GND
  D5  14    SLCK (SPI)
  D6  12    MISO (SPI)
  D7  13    MOSI (SPI)
  D8  15    CS (SPI)
  RX  03
  TX  01
  GND
  3.3V


  Caracterítica especiales
*/

//NO USA EL RESET, VER COMO SACARLO!
U8G2_SSD1306_128X32_UNIVISION_F_HW_I2C display(U8G2_R0, /* reset=*/16, /* clock=*/5, /* data=*/4);
/*
  U8G2_R0  No rotation, landscape
  U8G2_R1 90 degree clockwise rotation
  U8G2_R2 180 degree clockwise rotation
  U8G2_R3 270 degree clockwise rotation
  U8G2_MIRROR No rotation, landscape, display content is mirrored (v2.6.x)
*/

DHT dht(DHTPIN, DHTTYPE);

//String currentDir = "";
unsigned long lastButtonPress = 0;    //Antirebote botón al presionar
unsigned long lastButtonRelease = 0;  //Antirebote botón al soltar
unsigned long lastRotaryEncoder = 0;  //Antirebote rotary
unsigned long displayTime = 0;        //Tiempo de rotador de pantalla
unsigned long tiempoInicio = 0;       //Base de tiempo del reloj
unsigned long tiempoEncendido = 0;    //Sleep mode
unsigned long countLongPress = 0;     //Tiempo botón presionado
//unsigned long tiempoAlarma = 0;       //Duración de la alarma
//unsigned long simuPower = 0;              //Reloj simulación potencia

bool flagCLK;
bool flagPress = LOW;        //Flag de presión de botón
bool flagRelease = LOW;      //Flag de liberación de botón
bool flagLongpress = LOW;    //Flag de presión larga
bool activeLongpress = LOW;  //Flag de activación presión larga
bool upClk = LOW;            //Rotación encoder
bool downClk = LOW;          //Rotación encoder
bool flagTimer = LOW;        //Suma 1 segundo o 30 segundos
bool alarma = LOW;           //Código de alarma

int counter = 0;
int currentStateCLK;
int currentStateDT;
int lastStateCLK;
int lastStateDT;
int lastStateBTN = HIGH;

int cursorMenu = 0;     //Indicador menú o carrusel
int cursorDisplay = 0;  //Indicador de pantalla rotativa
int cursorLvl1 = 0;     //Indicador menú general
int cursorLvl2 = 1;     //Indicador submenú siempre inicia en 1



//**********************************************************************
//                          Personalizaciones
//**********************************************************************
const int submenuLength = 5;
const String menu[][submenuLength] = {
  //CONVERTIR EN UN VECTOR DE VECTORES PARA ENTENDER EL TAMAÑO
  { "Temperatura", "Set point", "Ripple", "Unidad", "Volver" },
  { "Reloj", "Modo", "Tiempo", "Reset", "Volver" },
  { "Ventilacion", "Modo", "Funcion", "Velocidad", "Volver" },
  { "Iluminacion", "Modo", "Alarma", "Brillo", "Volver" },
  { "Wifi", "Modo", "SSIS", "Nivel", "Volver" },
  { "Sistema", "Reiniciar", "Encoder", "Contraste", "Volver" },
  { "Salir" }
};

const int menuLength = (sizeof(menu) / sizeof(menu[0][0]) / submenuLength);

float menuVal[menuLength][submenuLength] = {};  //SE PUEDE COMPLETAR CON LAS VARIABLES?
/*
   menuVal[0][0] = Temperatura medida
   menuVal[0][1] = Temperatura seleccionada
   menuVal[0][2] = Ripple
   menuVal[0][3] = Unidad temperatura
   menuVal[0][4] = Humedad medida
   menuVal[1][0] = -
   menuVal[1][1] = Modo reloj (Off/Cronometro/Temporizador)
   menuVal[1][2] = Tiempo en milisegundos
   menuVal[1][3] = Reset
   menuVal[1][4] = -
   menuVal[2][0] = -
   menuVal[2][1] = Modo ventilacion (Manual/Automatico)
   menuVal[2][2] = Función ventilación (Progresivo/Simultáneo)
   menuVal[2][3] = Velocidad PWM
   menuVal[2][4] = -
   menuVal[3][0] = -
   menuVal[3][1] = Modo iluminación (Off/On)
   menuVal[3][2] = Alarma iluminación (Off/On)
   menuVal[3][3] = Brillo PWM
   menuVal[3][4] = -
   menuVal[4][0] = Modo WIFI (Scan/AP)
   menuVal[4][1] = SSID
   menuVal[4][2] = Potencia dBm
   menuVal[4][3] = -
   menuVal[4][4] = -
   menuVal[5][0] = -
   menuVal[5][1] = Reinicio
   menuVal[5][2] = Sensibilidad rotary encoder
   menuVal[5][3] = Contraste pantalla
   menuVal[5][4] = -
*/

const String modoReloj[] = { "OFF", "Cronometro", "Temporizador" };
const String modoVenti[] = { "Manual", "Automatico", "Ripple" };
const String funcVenti[] = { "Progresivo", "Simultaneo" };
const String unidTempe[] = { "C", "F" };
const String modoSINO[] = { "NO", "SI" };
const String modoOFFON[] = { "OFF", "ON" };


byte lightPWM = 0;   //Brillo de luz "on live"
int lightStep = 10;  //Pasos del dial de luz


//**********************************************************************
//                          Configuraciones
//**********************************************************************
int line0 = 10;                   //Primer linea de texto display
int line1 = 21;                   //Segunda linea de texto display
int line2 = 32;                   //Tercera linea de texto display
int displayRow = 121;             //Flechas de navegación
int eeAddress = 100;              //Location we want the data to be put.
const int eeOffset = eeAddress;   //Dirección desde donde comienza la memoria
unsigned int sleepTime = 600000;  //Tiempo para que entre en suspención

//**********************************************************************
//                          Prototipos
//**********************************************************************
void display2(void);
void renglones(String, String, String, int);
void displayLvl1(int);
void displayLvl2(int, int);
void displayLvl3(int, int);
void printHorario(void);
void printAntihorario(void);
void printBoton(void);
void progresivo(byte);
void power(void);
void softPWM(int);



void setup() {
  Serial.begin(115200);

  pinMode(CLK, INPUT_PULLUP);
  pinMode(DT, INPUT_PULLUP);
  pinMode(SW, INPUT_PULLUP);
  pinMode(LUZ, OUTPUT);
  pinMode(VT1, OUTPUT);
  pinMode(VT2, OUTPUT);

  lastStateCLK = digitalRead(CLK);

  //pinMode(LED_BUILTIN, OUTPUT); //Pin D0 (16)

  display.begin();
  display.setPowerSave(0);
  display.setDrawColor(2);
  display.setFontMode(1);
  display.setFont(u8g2_font_8x13_mf);
  display.setContrast(255);
  //display.setFont(u8g2_font_7x13B_mr);
  //display.setFont(u8g2_font_unifont_t_cyrillic);

  dht.begin();

  display.clearBuffer();
  display.setCursor(20, line1);
  display.print("Iniciando...");
  //El display tiene 16 posiciones horizontales
  //display.print("1234567891123456");
  //display.print("ABCDEFGHIJKLMNOP");
  display.sendBuffer();
  Serial.println("");

  //**********************************************************************
  //                Cargar de memoria las configuraciones
  //**********************************************************************
  EEPROM.begin(4096);

  delay(100);

  Serial.println("");
  //Cálculo tamaño de memoria
  Serial.println("Tamaño memoria: ");
  Serial.print("Menu: ");
  Serial.println(sizeof(menu));
  Serial.print("Menu[0][0]: ");
  Serial.println(sizeof(menu[0][0]));
  Serial.print("submenuLength: ");
  Serial.println(submenuLength);
  Serial.print("menuLength: ");
  Serial.println(menuLength);
  Serial.println("");
  Serial.println("Cargando memoria: ");
  for (int i = 0; i < menuLength - 1; i++) {
    for (int j = 0; j < submenuLength; j++) {
      EEPROM.get(eeAddress, menuVal[i][j]);
      Serial.print(eeAddress);
      Serial.print(" ");
      Serial.print(i);
      Serial.print(" ");
      Serial.print(j);
      Serial.print(" ");
      Serial.println(menuVal[i][j]);
      eeAddress += sizeof(menuVal[i][j]);
    }
  }

  if (eeAddress >= 4096) {
    Serial.println("Advertencia error overflow memoria EEPROM");
  }

  /*
    if( isnan(menuVal[i][j]) || menuVal[i][j]))
    {
    //Terminar de definir inicialización
    }
  */

  display.setContrast(menuVal[5][3]);
  lightPWM = menuVal[3][3];
  analogWrite(LUZ, lightPWM);
  //analogWrite(VT1, menuVal[2][3]);

  menuVal[0][4] = dht.readHumidity();
  menuVal[0][0] = dht.readTemperature();

  //Puede ser bloqueante!
  while (menuVal[0][0] <= -50) {
    delay(1000);
    menuVal[0][4] = dht.readHumidity();
    menuVal[0][0] = dht.readTemperature();
  }


  //Prueba de potencia
  //menuVal[0][0] = 0;
  //Prueba reconocimiento de sensor humedad
  //Serial.println(DHTTYPE);
}

void loop() {

  //**********************************************************************
  //                          Control del cursor
  //**********************************************************************
  //Rotación

  currentStateCLK = digitalRead(CLK);
  currentStateDT = digitalRead(DT);

  if (currentStateCLK == LOW && currentStateCLK != lastStateCLK) {

    flagCLK = HIGH;
    lastStateCLK = currentStateCLK;

  } else if (currentStateCLK == HIGH && currentStateCLK != lastStateCLK) {

    flagCLK = LOW;
    lastStateCLK = currentStateCLK;
  }

  if (flagCLK == HIGH) {

    if (currentStateDT == LOW && currentStateDT != lastStateDT) {

      if (millis() - lastRotaryEncoder > menuVal[5][2] * 2) {
        counter++;
        flagCLK = LOW;
        upClk = HIGH;
        downClk = LOW;
        tiempoEncendido = millis();
      }

    } else if (currentStateDT == HIGH && currentStateDT != lastStateDT) {

      if (millis() - lastRotaryEncoder > menuVal[5][2]) {
        counter--;
        flagCLK = LOW;
        upClk = LOW;
        downClk = HIGH;
        tiempoEncendido = millis();
      }
    }

  } else {
    lastRotaryEncoder = millis();
    lastStateDT = currentStateDT;
  }




  //**********************************************************************
  //                          Botón
  //**********************************************************************

  // Read the button state
  int btnState = digitalRead(SW);

  //If we detect LOW signal, button is pressed
  if (btnState == LOW && lastStateBTN == HIGH) {
    //if 50ms have passed since last LOW pulse, it means that the
    //button has been pressed, released and pressed again
    if (millis() - lastButtonPress > 50) {

      //Si la pantalla está apagada resetea el tiempo para que la encienda
      //Suspención 10 minutos 600000 milisegundos
      if (millis() - tiempoEncendido >= sleepTime) {
        //Enciende
        //display.setPowerSave(LOW);
        tiempoEncendido = millis();
      } else {
        flagPress = HIGH;
        flagLongpress = HIGH;
        activeLongpress = LOW;
        //flagRelease = LOW;
        countLongPress = millis();
        tiempoEncendido = millis();
      }

    } else {
      lastStateBTN = btnState;
    }

    // Remember last button press event
    lastButtonPress = millis();
  }
  //Si detecta señal HIGH y antes estaba presionado, el botón se liberó
  else if (btnState == HIGH && lastStateBTN == LOW) {
    //if 50ms have passed since last LOW pulse, it means that the
    //button has been pressed, released and pressed again
    if (millis() - lastButtonRelease > 50) {
      flagRelease = HIGH;
      flagLongpress = LOW;
    } else {
      lastStateBTN = btnState;
    }
    // Remember last button release event
    lastButtonRelease = millis();
  } else {

    lastStateBTN = btnState;
  }


  //Efectos sobre el botón
  if (flagPress == HIGH) {
    //flagPress = LOW;
    Serial.println("Button pressed!");
  }
  if (flagRelease == HIGH && activeLongpress == LOW) {
    //flagRelease = LOW;
    Serial.print("Button released! ");
    Serial.print(millis() - countLongPress);
    Serial.println(" mseg");
  }
  if (flagLongpress == HIGH) {
    if (millis() - countLongPress > 3000) {
      //flagLongpress = LOW;
      //activeLongpress = HIGH;
      Serial.println("Button pressed > 3seg");
    }
  }



  //**********************************************************************
  //                          Display
  //**********************************************************************
  //Pantalla principal

  switch (cursorMenu) {
    case 0:
      //Rota la pantalla cada 3 segundos
      if (millis() - displayTime >= 3000) {
        displayTime = millis();
        if (cursorDisplay == 0) {
          cursorDisplay++;

          menuVal[0][4] = dht.readHumidity();
          //Serial.println(menuVal[0][4]);
          menuVal[0][0] = dht.readTemperature();
          //Serial.println(t);

          String uno = String("Temperat. ") + String((int)menuVal[0][0]) + String("/") + String((int)menuVal[0][1]) + String(unidTempe[(int)menuVal[0][3]]);
          String dos = String("Humedad   ") + String((int)menuVal[0][4]) + String("%");
          String tres = String("Velocidad ") + String(map(menuVal[2][3], 0, 255, 0, 100)) + String("%");

          renglones(uno, dos, tres, 3);

        } else if (cursorDisplay == 1) {
          cursorDisplay = 0;
          display2();
        }
      } else if (cursorDisplay == 0) {

        display2();

      } else if (cursorDisplay == 2) {

        display.clearBuffer();
        display.setCursor(20, line1);
        display.print("ALARMA!!!!");
        display.sendBuffer();
      }

      //Al rotar el dial cambia la luz
      if (upClk == HIGH && cursorDisplay <= 2) {
        cursorDisplay = 1;
        displayTime = millis();
        upClk = LOW;
        if (lightPWM <= 255 - lightStep) {
          lightPWM = lightPWM + lightStep;
        } else if (lightPWM > 255 - lightStep) {
          lightPWM = 255;
        }
        display2();
        analogWrite(LUZ, lightPWM);
      } else if (downClk == HIGH && cursorDisplay <= 2) {
        cursorDisplay = 1;
        displayTime = millis();
        downClk = LOW;
        if (lightPWM >= 0 + lightStep) {
          lightPWM = lightPWM - lightStep;
        } else if (lightPWM < 0 + lightStep) {
          lightPWM = 0;
        }
        display2();
        analogWrite(LUZ, lightPWM);
      }

      //Efectos sobre el botón
      //Presiona
      if (flagPress == HIGH) {
        flagPress = LOW;
      }
      //Suelta
      if (flagRelease == HIGH && activeLongpress == LOW) {
        flagRelease = LOW;
        //Serial.print("Button released! ");
        //Serial.print(millis() - countLongPress);
        //Serial.println(" mseg");

        if (cursorDisplay <= 2) {
          cursorMenu++;
          //Falta condición de volver
          String uno = menu[cursorLvl1][0];
          String dos = menu[cursorLvl1 + 1][0];
          String tres = menu[cursorLvl1 + 2][0];
          renglones(uno, dos, tres, 0);
          printBoton();

        } else if (cursorDisplay == 2) {
          cursorDisplay = 0;
        }
      } else {
        flagRelease = LOW;
      }
      //Mantiene
      if (flagLongpress == HIGH) {
        if (millis() - countLongPress > 3000) {
          flagLongpress = LOW;
          activeLongpress = HIGH;
          //Serial.println("Button pressed > 3seg");

          //Si está encendido lo apaga
          if (cursorDisplay <= 2) {
            cursorDisplay = 3;
            display.clearBuffer();
            display.setCursor(20, line1);
            display.print("Apagando...");
            display.sendBuffer();
            Serial.println("");
            delay(500);
            analogWrite(VT1, 0);
            delay(500);
            analogWrite(VT2, 0);
            delay(500);
            analogWrite(LUZ, 0);
            delay(500);
            display.setPowerSave(HIGH);
          } else {
            //Si está en standby lo enciende
            cursorDisplay = 0;
            display.setPowerSave(LOW);
            display.clearBuffer();
            display.setCursor(20, line1);
            display.print("Iniciando...");
            display.sendBuffer();
            Serial.println(" ");
            Serial.println(" ");
            Serial.println("Iniciando...");
            delay(500);
            tiempoInicio = millis();
          }
        }
      }

      break;

    //Primer menú general
    case 1:

      //Al rotar el dial cambia el renglon
      if (upClk == HIGH && downClk == LOW) {
        upClk = LOW;
        if (cursorLvl1 < menuLength - 1) {
          cursorLvl1++;
          displayLvl1(cursorLvl1);
          printHorario();
        }

      } else if (downClk == HIGH && upClk == LOW) {
        downClk = LOW;
        if (cursorLvl1 > 0) {
          cursorLvl1--;
          displayLvl1(cursorLvl1);
          printAntihorario();
        }
      }

      //Efectos sobre el botón
      if (flagPress == HIGH) {
        flagPress = LOW;
        //Serial.println("Button pressed!");

        if (menu[cursorLvl1][0] == "Salir") {
          activeLongpress = HIGH;
          cursorMenu--;
          cursorLvl1 = 0;
          displayLvl1(cursorLvl1);
          //String uno = menu[cursorLvl1][0];
          //String dos = menu[cursorLvl1][1];
          //String tres = menu[cursorLvl1][2];
          //renglones(uno, dos, tres, 0);
          printBoton();
        } else {
          cursorMenu++;
          displayLvl2(cursorLvl1, cursorLvl2);
          //String uno = menu[cursorLvl1][1];
          //String dos = menu[cursorLvl1][2];
          //String tres = menu[cursorLvl1][3];
          //renglones(uno, dos, tres, 0);
          printBoton();
        }
      }
      if (flagRelease == HIGH && activeLongpress == LOW) {
        flagRelease = LOW;
      } else {
        flagRelease = LOW;
      }


      break;

    //Opción submenú
    case 2:
      //Al rotar el dial cambia el renglon
      if (upClk == HIGH) {
        upClk = LOW;
        if (cursorLvl2 < submenuLength - 1) {
          if (menu[cursorLvl1][cursorLvl2] != "Volver") {
            cursorLvl2++;
            printHorario();
          }
          displayLvl2(cursorLvl1, cursorLvl2);
        }
      } else if (downClk == HIGH) {
        downClk = LOW;
        if (cursorLvl2 > 1) {
          cursorLvl2--;
          displayLvl2(cursorLvl1, cursorLvl2);
          printAntihorario();
        }
      }

      //Efectos sobre el botón
      if (flagPress == HIGH) {
        flagPress = LOW;
        //Serial.println("Button pressed!");

        if (menu[cursorLvl1][cursorLvl2] == "Volver") {
          cursorMenu--;
          cursorLvl2 = 1;  //El cursor de segundo nivel no puede ser menor a 1
          displayLvl1(cursorLvl1);
          printBoton();
        } else {
          cursorMenu++;
          activeLongpress = HIGH;
          displayLvl3(cursorLvl1, cursorLvl2);
          printBoton();
        }
      }
      if (flagRelease == HIGH && activeLongpress == LOW) {
        flagRelease = LOW;
      } else {
        flagRelease = LOW;
      }
      break;


    //Configuración de valores del submenú
    case 3:

      /*
         menuVal[0][0] = Temperatura medida
         menuVal[0][1] = Temperatura seleccionada
         menuVal[0][2] = Ripple
         menuVal[0][3] = Unidad temperatura
         menuVal[0][4] = Humedad medida
         menuVal[1][0] = -
         menuVal[1][1] = Modo reloj (Off/Cronometro/Temporizador)
         menuVal[1][2] = Tiempo en milisegundos
         menuVal[1][3] = Reset
         menuVal[1][4] = -
         menuVal[2][0] = -
         menuVal[2][1] = Modo ventilacion (Manual/Automatico)
         menuVal[2][2] = Función ventilación (Progresivo/Simultáneo)
         menuVal[2][3] = Velocidad PWM
         menuVal[2][4] = -
         menuVal[3][0] = -
         menuVal[3][1] = Modo iluminación (Off/On)
         menuVal[3][2] = Alarma iluminación (Off/On)
         menuVal[3][3] = Brillo PWM
         menuVal[3][4] = -
         menuVal[4][0] = Modo WIFI (Scan/AP)
         menuVal[4][1] = SSID
         menuVal[4][2] = Porencia dBm
         menuVal[4][3] = -
         menuVal[4][4] = -
         menuVal[5][0] = -
         menuVal[5][1] = Reinicio
         menuVal[5][2] = Sensibilidad rotary encoder
         menuVal[5][3] = Contraste pantalla
         menuVal[5][4] = -
      */

      //Al rotar el dial cambia el valor de configuración
      if (upClk == HIGH) {
        upClk = LOW;

        //Temperatura seleccionada
        if (cursorLvl1 == 0 && cursorLvl2 == 1) {
          //Para °C el límite es 99 y para °F es 210
          if (menuVal[cursorLvl1][cursorLvl2] < ((210 - 99) * menuVal[0][3] + 99)) {
            menuVal[cursorLvl1][cursorLvl2]++;
          }
        }
        //Riple
        else if (cursorLvl1 == 0 && cursorLvl2 == 2) {
          //Para °C el límite es 10 y para °F es 18
          if (menuVal[cursorLvl1][cursorLvl2] < ((18 - 10) * menuVal[0][3] + 10)) {
            menuVal[cursorLvl1][cursorLvl2]++;
          }
        }
        //Unidad temperatura
        else if (cursorLvl1 == 0 && cursorLvl2 == 3) {
          //Pasó a °F
          if (menuVal[cursorLvl1][cursorLvl2] < sizeof(unidTempe) / sizeof(unidTempe[0]) - 1) {
            menuVal[cursorLvl1][cursorLvl2]++;
            //Conversión de °C a °F: °F = (°C x 1.8) + 32
            //Conversión de °F a °C: °C = (°F - 32) / 1.8

            //menuVal[0][1] = round(menuVal[0][1] * 1.8 + 32);
            //menuVal[0][2] = round(menuVal[0][2] * 1.8 + 32);
          }
        }
        //Modo reloj
        else if (cursorLvl1 == 1 && cursorLvl2 == 1) {
          if (menuVal[cursorLvl1][cursorLvl2] < sizeof(modoReloj) / sizeof(modoReloj[0]) - 1) {
            menuVal[cursorLvl1][cursorLvl2]++;
          }
        }
        //Tiempo reloj
        else if (cursorLvl1 == 1 && cursorLvl2 == 2) {

          //Si flagTimer es 0 suma 1 minuto si flagTimer es 1 suma 30 minutos
          menuVal[cursorLvl1][cursorLvl2] = menuVal[cursorLvl1][cursorLvl2] + 60000 + (flagTimer * 29 * 60000);
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

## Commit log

2023-04-03 Versión 0.0
    V00: Versión inicial
    * Rotary encoder
    * Push button
    * Termómetro y Humedad
    * Display y menú
2023-04-03 V0.1
    V01: Bug rotary encoder
    * Zig-zag bug y switch antirrebote
    * Manejo de memoria EEPROM (No tiene interna)
    [Eclosure3D.ino]
2023-04-03 V0.2
    V02: mcu esp8266
    * Eeprom update float
    * Rotary debounce
    * Bug commit eeprom
    * Flechas navegación level 3
    * En iniciando espera temperatura y humerar
    * Reset modo fábrica cargar variables en memoria
    * Botón long press
    * Long press tiempo reloj horas
    * Carrusel tiempo continuo display
    * Límite de setpoint y riple para unidad de medida
    * Al cambiar la unidad de medida guarda los nuevos valores. setpoint y riple.
    * Temperatura °F/°C, con conversión
    * Centrar modos level 3
    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
    [Eclosure3D.ino]
2023-04-03 Historial de features de las versiones
2023-04-23 Cambio de carpeta
2023-05-10 Update README.md
    Máquina de estados general
2023-05-13 Perspectiva de componentes
2023-06-08 Previsualización de imágenes.md
2024-02-24 Create Bug rebote rotary encoder.md
2024-02-24 Update Bug rebote rotary encoder.md
2024-03-16 Bug rotary encoder
2024-05-14 Create Fuente switching.md
2024-05-14 Rename PCB/Enclosure3D Componentes prototipo.png to PCB/Imagenes/Enclosure3D Componentes prototipo.png
2024-05-14 Rename PCB/Enclosure3D Perspectiva Componentes.png to PCB/Imagenes/Enclosure3D Perspectiva Componentes.png
2024-05-14 Cambio de resistencias tensión fija
2024-05-14 Update Fuente switching.md
2024-05-14 Diagrama Schematico
2024-05-16 Tabla de compatibilidad
2024-05-16 Silkscreen PCB
